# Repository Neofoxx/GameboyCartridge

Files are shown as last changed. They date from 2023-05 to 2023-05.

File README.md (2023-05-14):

# Gameboy Cartridge with a PIC32

A Gameboy cartridge with a microcontroller on it, for quick tests on actual hardware 

## Overview

This projects implements a simple 32kB ROM + 8kB SRAM cartridge, where both are replaced with SRAM chips, and populated by a PIC32MM microcontroller at either boot, or via a USB interface.

Currently working:
- Uploading to the "ROM" part of the cartridge
- Resetting etc.
- Tested that Tetris is playable, if a write to 0x2000 is patched out

Future plans:
- "SRAM" part of cartridge tested
- Speedup of upload/readout scripts

Not planned:
- Bigger size of "ROM"

## Theory of operation

In a normal gameboy cartrdige without an MBC, there is usually just a ROM chip, that contains the game. An exmaple of this would be Tetris. This is memory mapped into the Gameboys address space, and can be 32kB max.

There is also space for an 8kB RAM chip - usually SRAM, which means a battery is required to save the contents. FRAM chips are available nowadays, and remove the battery requirements, at the expense of increased cost. This is also memory mapped, but needs a few logic for address decoding.

In this implementation, both ROM and RAM are replaced with 32kB SRAM chips. One is used as the ROM, the other (well, part of it) is used as SRAM.

The idea is, that for speeds testing on real HW, code can be uploaded from the PC to the Gameboy via the USB connection, removing the need to unplug the cartridge, insert it into the programmer, flash it, remove it, reinstall it, and then test. Convenience is what we're after.

The other idea is for the microcontroller to have a 40kB section of FLASH dedicated to storing said contents, and automatically populating the chips at power-up.

## TODOs

Fix board files. Forgot to connect some pins to the transistors...

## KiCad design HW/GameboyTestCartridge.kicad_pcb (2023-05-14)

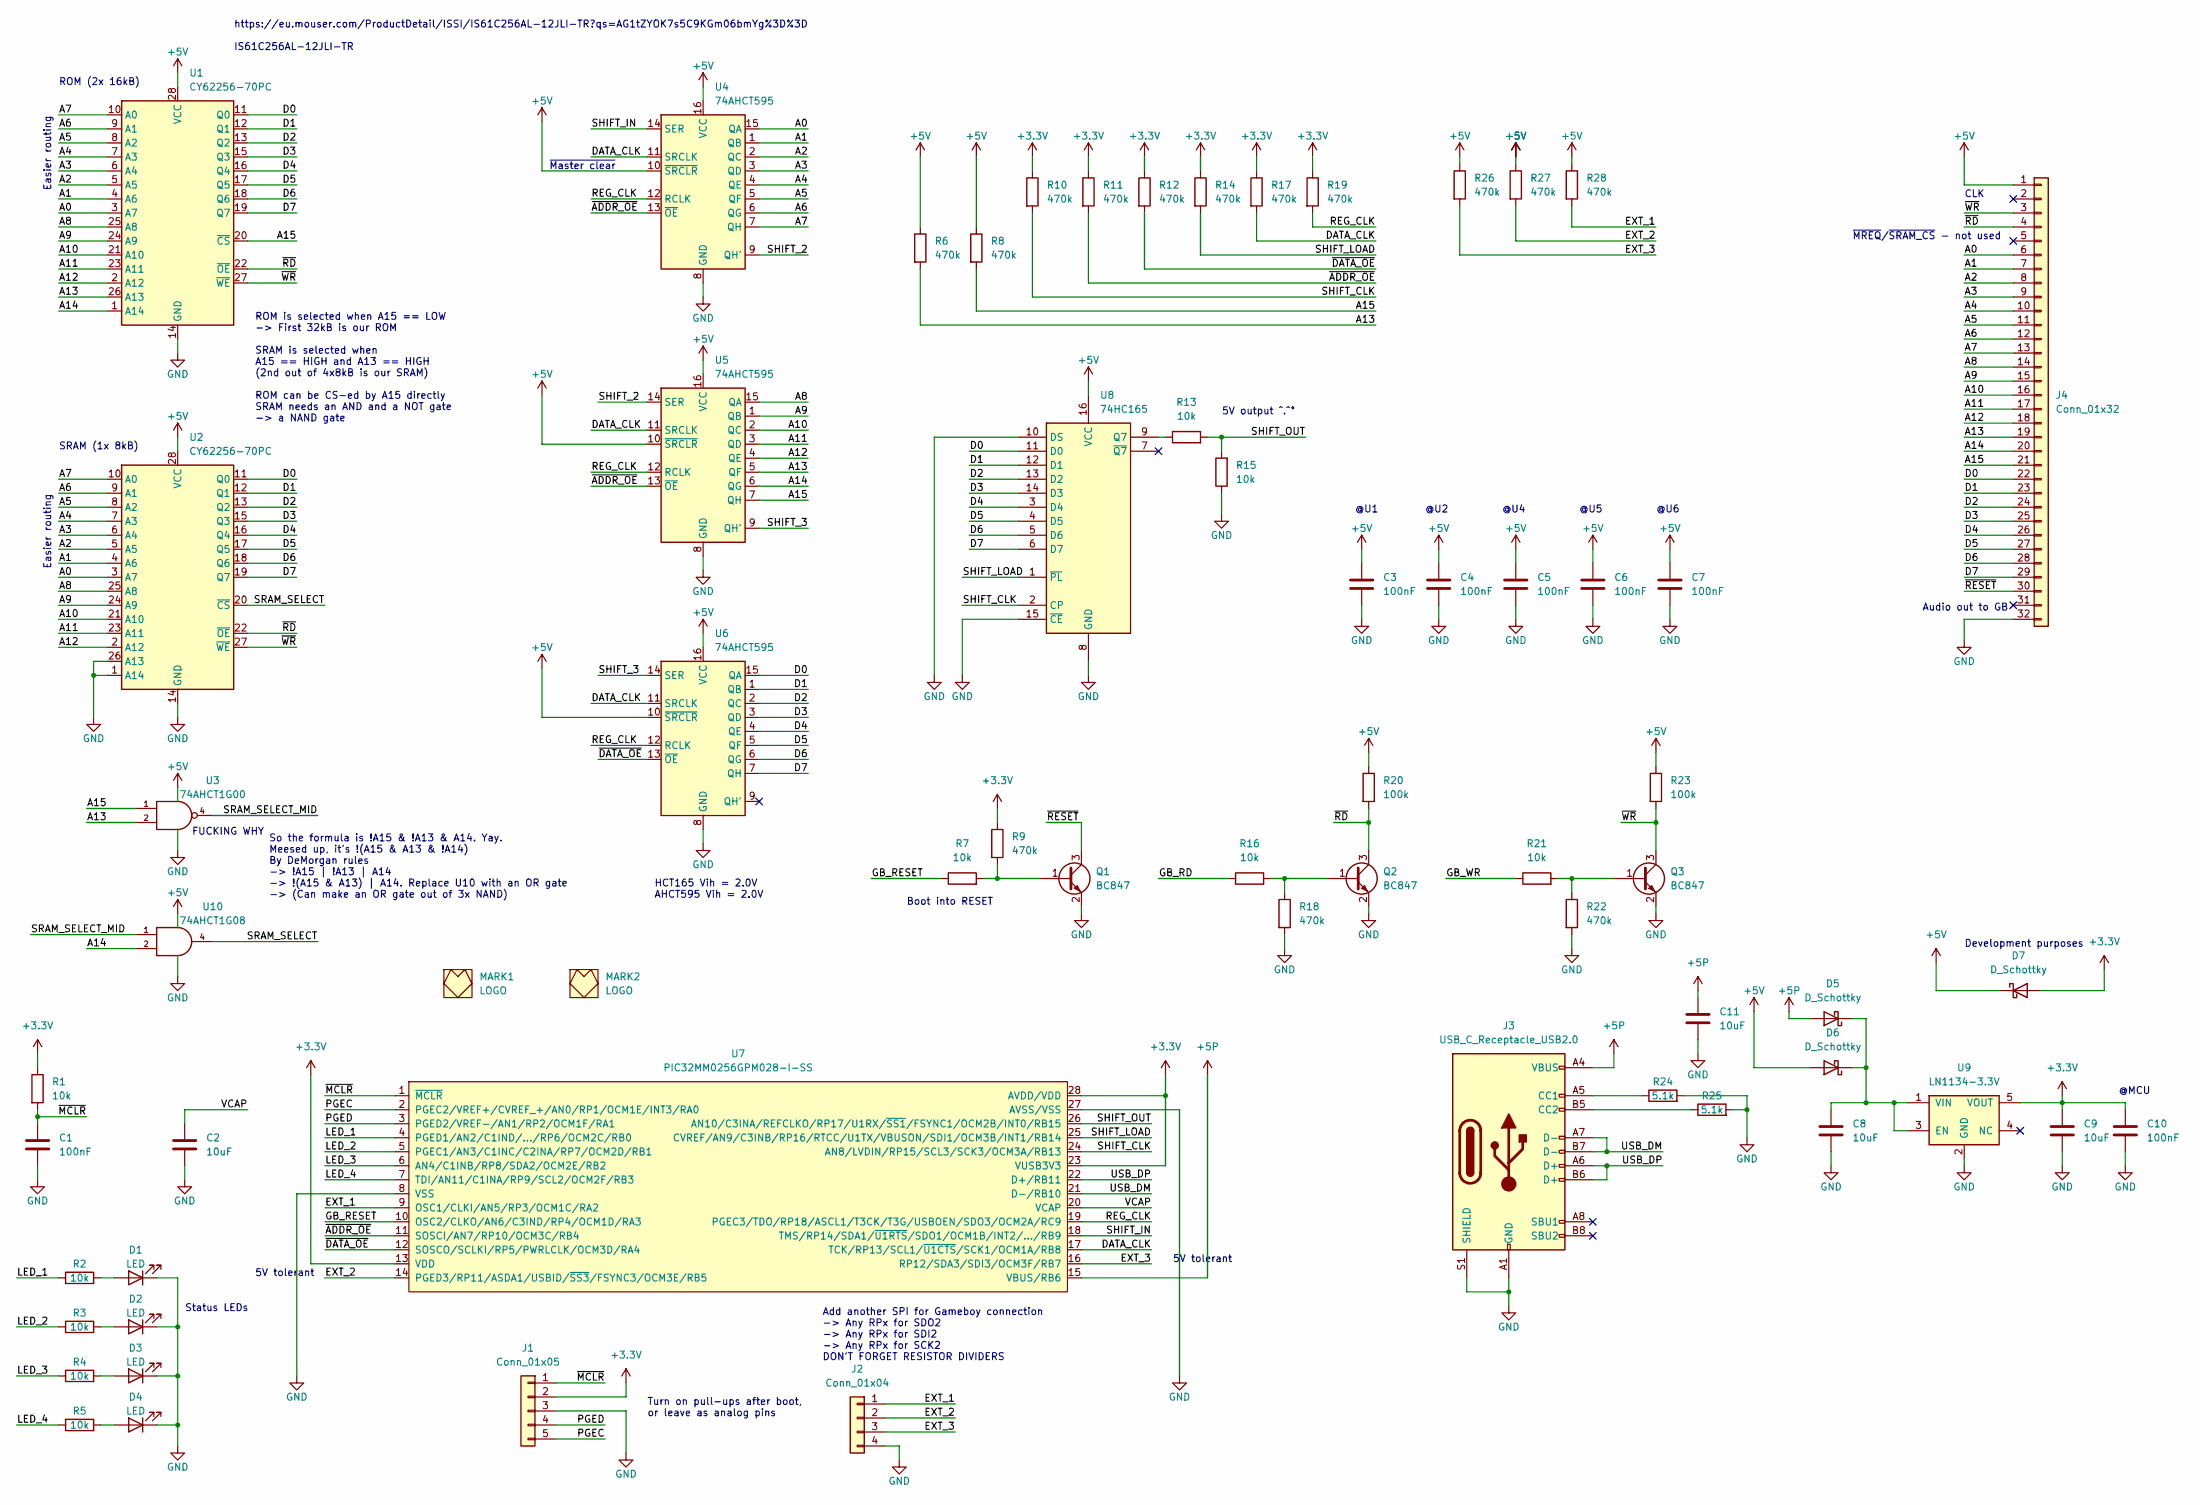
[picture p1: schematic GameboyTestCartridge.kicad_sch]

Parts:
C1, C3, C4, C5, C6, C7, C10: 100nF; C_0603_1608Metric
C2, C8, C9, C11: 10uF; C_0805_2012Metric
D1, D2, D3, D4: LED; LED_0603_1608Metric
D5, D6, D7: D_Schottky; D_SOD-323
J1: Conn_01x05; PinHeader_1x05_P2.54mm_Horizontal
J2: Conn_01x04; PinHeader_1x04_P2.54mm_Horizontal
J3: USB_C_Receptacle_USB2.0; Jing_USB_C_2_0_16pin_receptable_noSlots
J4: Conn_01x32; GameboyCartridge
MARK1: LOGO; FOX_LOGO_MASK
MARK2: LOGO; FOX_LOGO_SILK
Q1, Q2, Q3: BC847; SOT-23
R1, R2, R3, R4, R5, R7, R13, R15, R16, R21: 10k; R_0603_1608Metric
R6, R8, R9, R10, R11, R12, R14, R17, R18, R19, R22, R26, R27, R28: 470k; R_0603_1608Metric
R20, R23: 100k; R_0603_1608Metric
R24, R25: 5.1k; R_0603_1608Metric
U1, U2: CY62256-70PC; SOIC-28W_7.5x17.9mm_P1.27mm
U3: 74AHCT1G00; SOT-23-5
U4, U5, U6: 74AHCT595; SOIC-16_3.9x9.9mm_P1.27mm
U7: PIC32MM0256GPM028-I-SS; SSOP-28_5.3x10.2mm_P0.65mm
U8: 74HC165; SOIC-16_3.9x9.9mm_P1.27mm
U9: LN1134-3.3V; SOT-23-5
U10: 74AHCT1G08; SOT-23-5

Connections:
+3.3V: C9.1, C10.1, D7.2 (A), J1.2, R1.1, R9.1, R10.1, R11.1, R12.1, R14.1, R17.1, R19.1, U7.13 (VDD), U7.23 (VUSB3V3), U7.28 (AVDD/VDD), U9.5 (VOUT)
+5P: C11.1, D5.2 (A), J3.A4 (VBUS), J3.A9 (VBUS), J3.B4 (VBUS), J3.B9 (VBUS), U7.15 (VBUS/RB6)
+5V: C3.1, C4.1, C5.1, C6.1, C7.1, D6.2 (A), D7.1 (K), J4.1, R6.1, R8.1, R20.1, R23.1, R26.1, R27.1, R28.1, U1.28 (VCC), U2.28 (VCC), U3.5 (VCC), U4.10 (~SRCLR), U4.16 (VCC), U5.10 (~SRCLR), U5.16 (VCC), U6.10 (~SRCLR), U6.16 (VCC), U8.16 (VCC), U10.5 (VCC)
/A0: J4.6, U1.3 (A7), U2.3 (A7), U4.15 (QA)
/A1: J4.7, U1.4 (A6), U2.4 (A6), U4.1 (QB)
/A2: J4.8, U1.5 (A5), U2.5 (A5), U4.2 (QC)
/A3: J4.9, U1.6 (A4), U2.6 (A4), U4.3 (QD)
/A4: J4.10, U1.7 (A3), U2.7 (A3), U4.4 (QE)
/A5: J4.11, U1.8 (A2), U2.8 (A2), U4.5 (QF)
/A6: J4.12, U1.9 (A1), U2.9 (A1), U4.6 (QG)
/A7: J4.13, U1.10 (A0), U2.10 (A0), U4.7 (QH)
/A8: J4.14, U1.25 (A8), U2.25 (A8), U5.15 (QA)
/A9: J4.15, U1.24 (A9), U2.24 (A9), U5.1 (QB)
/A10: J4.16, U1.21 (A10), U2.21 (A10), U5.2 (QC)
/A11: J4.17, U1.23 (A11), U2.23 (A11), U5.3 (QD)
/A12: J4.18, U1.2 (A12), U2.2 (A12), U5.4 (QE)
/A13: J4.19, R6.2, U1.26 (A13), U3.2, U5.5 (QF)
/A14: J4.20, U1.1 (A14), U5.6 (QG), U10.2
/A15: J4.21, R8.2, U1.20 (~CS), U3.1, U5.7 (QH)
/D0: J4.22, U1.11 (Q0), U2.11 (Q0), U6.15 (QA), U8.11 (D0)
/D1: J4.23, U1.12 (Q1), U2.12 (Q1), U6.1 (QB), U8.12 (D1)
/D2: J4.24, U1.13 (Q2), U2.13 (Q2), U6.2 (QC), U8.13 (D2)
/D3: J4.25, U1.15 (Q3), U2.15 (Q3), U6.3 (QD), U8.14 (D3)
/D4: J4.26, U1.16 (Q4), U2.16 (Q4), U6.4 (QE), U8.3 (D4)
/D5: J4.27, U1.17 (Q5), U2.17 (Q5), U6.5 (QF), U8.4 (D5)
/D6: J4.28, U1.18 (Q6), U2.18 (Q6), U6.6 (QG), U8.5 (D6)
/D7: J4.29, U1.19 (Q7), U2.19 (Q7), U6.7 (QH), U8.6 (D7)
/DATA_CLK: R17.2, U4.11 (SRCLK), U5.11 (SRCLK), U6.11 (SRCLK), U7.17 (TCK/RP13/SCL1/~U1CTS/SCK1/OCM1A/RB8)
/EXT_1: J2.1, R28.2, U7.9 (OSC1/CLKI/AN5/RP3/OCM1C/RA2)
/EXT_2: J2.2, R27.2, U7.14 (PGED3/RP11/ASDA1/USBID/~SS3/FSYNC3/OCM3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)
/EXT_3: J2.3, R26.2, U7.16 (RP12/SDA3/SDI3/OCM3F/RB7)
/GB_RD: R16.1
/GB_RESET: R7.1, U7.10 (OSC2/CLKO/AN6/C3IND/RP4/OCM1D/RA3)
/GB_WR: R21.1
/LED_1: R2.1, U7.4 (PGED1/AN2/C1IND/.../RP6/OCM2C/RB0)
/LED_2: R3.1, U7.5 (PGEC1/AN3/C1INC/C2INA/RP7/OCM2D/RB1)
/LED_3: R4.1, U7.6 (AN4/C1INB/RP8/SDA2/OCM2E/RB2)
/LED_4: R5.1, U7.7 (TDI/AN11/C1INA/RP9/SCL2/OCM2F/RB3)
/PGEC: J1.5, U7.2 (PGEC2/VREF+/CVREF_+/AN0/RP1/OCM1E/INT3/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)
/PGED: J1.4, U7.3 (PGED2/VREF-/AN1/RP2/OCM1F/RA1)
/REG_CLK: R19.2, U4.12 (RCLK), U5.12 (RCLK), U6.12 (RCLK), U7.19 (PGEC3/TDO/RP18/ASCL1/T3CK/T3G/USBOEN/SD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)
/SHIFT_2: U4.9 (QH'), U5.14 (SER)
/SHIFT_3: U5.9 (QH'), U6.14 (SER)
/SHIFT_CLK: R10.2, U7.24 (AN8/LVDIN/RP15/SCL3/SCK3/OCM3A/RB13), U8.2 (CP)
/SHIFT_IN: U4.14 (SER), U7.18 (TMS/RP14/SDA1/~U1RTS/SDO1/OCM1B/INT2/..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)
/SHIFT_LOAD: R14.2, U7.25 (CVREF/AN9/C3INB/RP16/RTCC/U1TX/VBUSON/S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), U8.1 (~PL)
/SHIFT_OUT: R13.2, R15.2, U7.26 (AN10/C3INA/REFCLKO/RP17/U1RX/~SS1/FSYNC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)
/SRAM_SELECT: U2.20 (~CS), U10.4
/SRAM_SELECT_MID: U3.4, U10.1
/USB_DM: J3.A7 (D-), J3.B7 (D-), U7.21 (D-/RB10)
/USB_DP: J3.A6 (D+), J3.B6 (D+), U7.22 (D+/RB11)
/VCAP: C2.1, U7.20 (VCAP)
/~ADDR_OE: R11.2, U4.13 (~OE), U5.13 (~OE), U7.11 (SOSCI/AN7/RP10/OCM3C/RB4)
/~DATA_OE: R12.2, U6.13 (~OE), U7.12 (SOSCO/SCLKI/RP5/PWRLCLK/OCM3D/RA4)
/~MCLR: C1.1, J1.1, R1.2, U7.1 (~MCLR)
/~RD: J4.4, Q2.3 (C), R20.2, U1.22 (~OE), U2.22 (~OE)
/~RESET: J4.30, Q1.3 (C)
/~WR: J4.3, Q3.3 (C), R23.2, U1.27 (~WE), U2.27 (~WE)
GND: C1.2, C2.2, C3.2, C4.2, C5.2, C6.2, C7.2, C8.2, C9.2, C10.2, C11.2, D1.1 (K), D2.1 (K), D3.1 (K), D4.1 (K), J1.3, J2.4, J3.A1 (GND), J3.A12 (GND), J3.B1 (GND), J3.B12 (GND), J3.S1 (SHIELD), J4.32, Q1.2 (E), Q2.2 (E), Q3.2 (E), R15.1, R18.2, R22.2, R24.2, R25.2, U1.14 (GND), U2.1 (A14), U2.14 (GND), U2.26 (A13), U3.3 (GND), U4.8 (GND), U5.8 (GND), U6.8 (GND), U7.8 (VSS), U7.27 (AVSS/VSS), U8.8 (GND), U8.10 (DS), U8.15 (~CE), U9.2 (GND), U10.3 (GND)
unnamed: C8.1, D5.1 (K), D6.1 (K), U9.1 (VIN), U9.3 (EN)
unnamed: D1.2 (A), R2.2
unnamed: D2.2 (A), R3.2
unnamed: D3.2 (A), R4.2
unnamed: D4.2 (A), R5.2
unnamed: J3.A5 (CC1), R24.1
unnamed: J3.B5 (CC2), R25.1
unnamed: Q1.1 (B), R7.2, R9.2
unnamed: Q2.1 (B), R16.2, R18.1
unnamed: Q3.1 (B), R21.2, R22.1
unnamed: R13.1, U8.9 (Q7)

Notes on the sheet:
ROM is selected when A15 == LOW -> First 32kB is our ROM SRAM is selected when A15 == HIGH and A13 == HIGH (2nd out of 4x8kB is our SRAM) ROM can be CS-ed by A15 directly SRAM needs an AND and a NOT gate -> a NAND gate
HCT165 Vih = 2.0V AHCT595 Vih = 2.0V
Easier routing
5V output ^.^°
Turn on pull-ups after boot, or leave as analog pins
~{Master clear}
@U5
~{MREQ}/~{SRAM_CS} - not used
@U4
FUCKING WHY
@U2
Boot into RESET
So the formula is !A15 & !A13 & A14. Yay. Meesed up, it's !(A15 & A13 & !A14) By DeMorgan rules -> !A15 | !A13 | A14 -> !(A15 & A13) | A14. Replace U10 with an OR gate -> (Can make an OR gate out of 3x NAND)
Add another SPI for Gameboy connection -> Any RPx for SDO2 -> Any RPx for SDI2 -> Any RPx for SCK2 DON'T FORGET RESISTOR DIVIDERS
Audio out to GB
5V tolerant
Development purposes
@U1
Status LEDs
ROM (2x 16kB)
SRAM (1x 8kB)
@U6
https://eu.mouser.com/ProductDetail/ISSI/IS61C256AL-12JLI-TR?qs=AG1tZYOK7s5C9KGm06bmYg%3D%3D IS61C256AL-12JLI-TR
@MCU
CLK

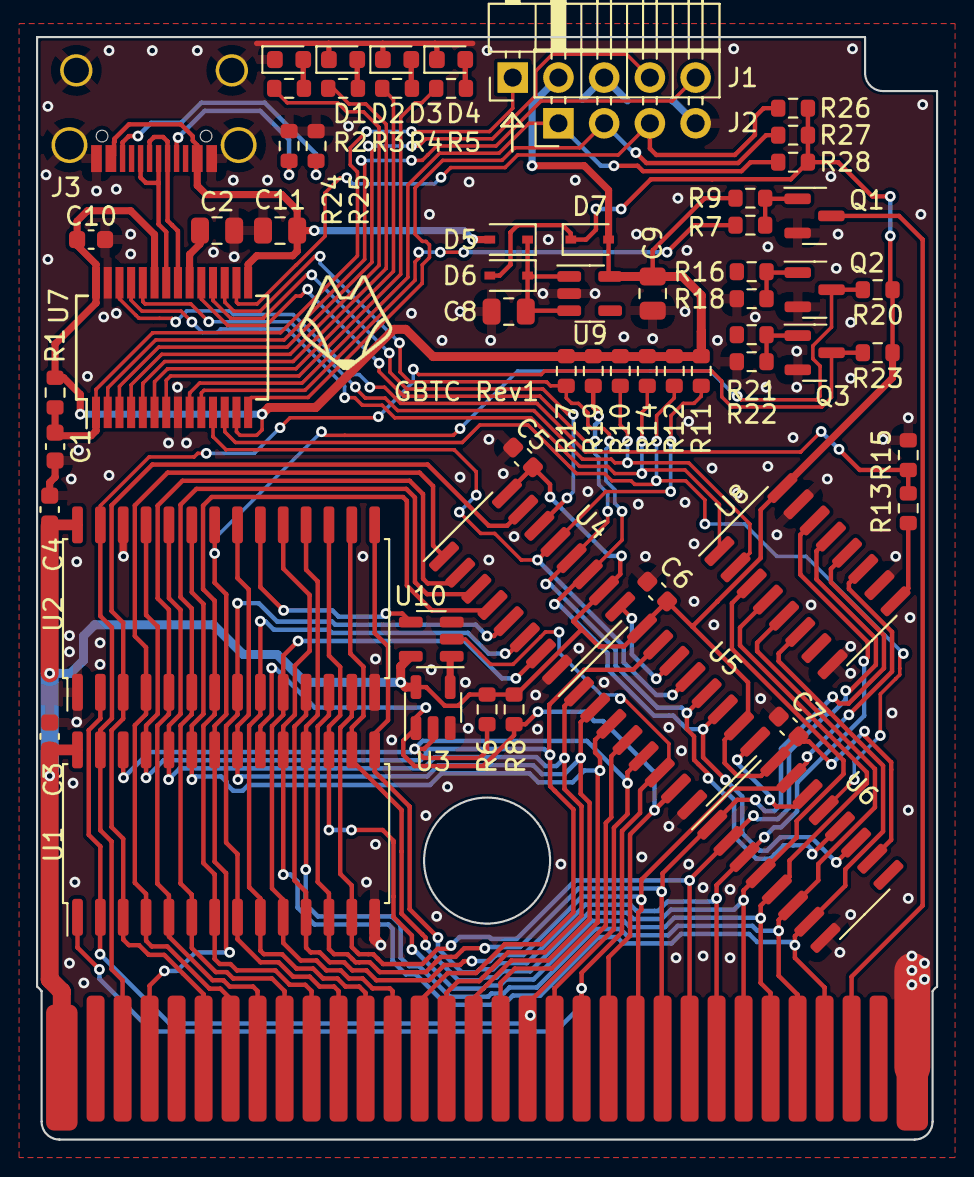
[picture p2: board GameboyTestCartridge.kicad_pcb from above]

Board: 2 copper layers, 50.0 x 61.2 mm, 65 parts (1 on the bottom side), 68 nets.

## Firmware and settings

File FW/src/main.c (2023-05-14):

#include <p32xxxx.h>
#include <const.h>      // MIPS32
#include <inttypes.h>
#include <stdbool.h>
#include <string.h>
#include <stdio.h>
#include <newlib.h>
#include <errno.h>

// Config bits
#include <configBits.h>

// Drivers for HW
#include <GPIODrv.h>
#include <LED.h>
// USB
#include <usb.h>
#include <usb_config.h>
#include <usb_ch9.h>
#include <usb_cdc.h>
// COMMS - usb and UART
#include <COMMS.h>
// Interrupts
#include <interrupt.h>

// Commands
#include <commandExecutor.h>

// Delay
#include <support.h>

char inBuf[2048];

// Not actually used
static struct cdc_line_coding line_coding =
{
	115200,
	CDC_CHAR_FORMAT_1_STOP_BIT,
	CDC_PARITY_NONE,
	8,
};

volatile uint32_t packetCounter = 0;	// Reset by SOF. May be useful


// TODO - run the timer, like in MX440 example (SysTick style)
// TODO2 - there should be an implementation, that uses the 24MHz/2 clock using CP0
void simpleDelay(unsigned int noOfLoops){
    unsigned int i = 0;
    while (i<noOfLoops){
        i++;
        asm("nop");
    }
}

void setup(){

	// Disable JTAG pins!

	GPIODrv_init();
	LED_init();
	
    // Check, there was a bug in one of the versions...
	//uint32_t * ANSELB_REAL = (uint32_t *)0xBF802BB0;
	//ANSELB_REAL[0] = 0;

	// Copied for USB, from hardware.c
	IPC7bits.USBIP = 4;

	// Enable interrupts - at the end, otherwise setting priorities is ineffective ? TODO
	//INTEnableSystemMultiVectoredInt();
	// PIC32MM needs some hand work
	SYSKEY = 0x00000000;      // force lock
	SYSKEY = 0xAA996655;      // unlock
	SYSKEY = 0x556699AA; 

	SPLLCON = (0b010 << 24)	// PLLODIV = PLL divide-by-4, so we get 24MHZ from 96MHz
		| (0b0000101 << 16)		// PLLMULT = x12, so 8MHz * 12 = 96MHz
		| (0b1 << 7);			// FRC is selected as input to PLL

	simpleDelay(1000);

	OSCCONbits.NOSC = 1;	// Switch to SPLL
	
	OSCCONSET = 1;		// Sets the OSWEN bit, that forces a change to news settings in NOSC
	
	SYSKEY = 0x00000000;    // force lock

	simpleDelay(100000);


	// Setup oscillator tuning, because we're too cool for crystals
	SYSKEY = 0x00000000;      // force lock
	SYSKEY = 0xAA996655;      // unlock
	SYSKEY = 0x556699AA; 
	
	OSCTUN = (1<<12) 		// SOSC host clock used to tune
		| (0b100000 << 0);	// Set to -1.5% off, just to see on scope.	
		
	simpleDelay(400000);	
		
	OSCTUNSET = (1<<15);	// Set ON bit, to start tuning.	
	
	SYSKEY = 0x00000000;      // force lock

	simpleDelay(100000);
	
	REFO1TRIM = 0;
	
	REFO1CON = (48 << 16)	// Divde input by 2*(val + TRIM/512). 2 == 4
		| (1 << 15)			// ON bit
		| (0 << 12)			// NOT Driven on REFO1 pin
		| (1 << 11)			// Continues in sleep mode
		| (0b0111);			// PLL VCO is input to REFCLK
	
	
	
	
	// Basically INTEnableSystemMultiVectoredInt
	// Enable multi-vectored mode
	//INTCONSET = _INTCON_MVEC_MASK;
	//INTCON = INTCON | _INTCON_MVEC_MASK;
	INTCONbits.MVEC=1; 

	// Interrupt exceptions use their own dedication exception vector offset (0x200), when CAUSE_IV is set to 1
	_CP0_BIS_CAUSE(_CP0_CAUSE_IV_MASK);

	// set the CP0 status IE bit high to turn on interrupts
	//INTEnableInterrupts();
	asm("ei");
	
}


int main(){

	setup();
	usb_init();
	
	IEC0bits.USBIE = 1;

	char outBuf[128];
	int len;

	int counter = 0;



	for(;;){
	
		len = sprintf(outBuf, "This is a test %d %d\n", counter++, COMMS_helper_dataLen(&uartRXstruct));

		//COMMS_helper_addToBuf(&uartTXstruct, (uint8_t *)outBuf, len);

		// At this point, check if there is a \n in the input buffer
		// If there isn't a \n for x chars, clear buffer or something
		// If there is, go parse the string.

		//delayMs(500);

		int32_t elements = COMMS_helper_checkNewline(&uartRXstruct);
		if (elements > 0){
			COMMS_helper_getData(&uartRXstruct, elements, (uint8_t *)inBuf);
			inBuf[elements] = 0;		// Null terminate
			inBuf[elements - 1] = 0;	// Delete newline

			commandExecutor(inBuf);

		}

		// Unused
		#ifndef USB_USE_INTERRUPTS
		usb_service();
		#endif

	}

    return(0);
    
}




/////////////////////////////////////////////////////////////7

#ifdef USB_USE_INTERRUPTS
#if defined (__PIC32MX__)

INTERRUPT(USB1Interrupt){

#elif defined (__PIC32MM__)

INTERRUPT(USBInterrupt){

#endif
  usb_service();  // Deal with USB stuff

  // All of the cases depend on this anyway.
  if (!usb_is_configured()){
    return;
  }

  // Priorities!

  // 3. We have one IN (us->PC) endpoint 
  // 2. We have one OUT (PC->us) endpoint


  ////////////////////////////////////////////////////////////
  // 2. Get data from EP2 OUT (PC to us)
  ////////////////////////////////////////////////////////////
  if (!usb_out_endpoint_halted(EP_UARTINTERFACE_NUM) && usb_out_endpoint_has_data(EP_UARTINTERFACE_NUM) && !usb_in_endpoint_busy(EP_UARTINTERFACE_NUM)) {

    if (!COMMS_uartRX_addToBuf()){
      // Packet is consumed regardless
    }

  }

  ////////////////////////////////////////////////////////////
  // 3. Push data to EP2 IN (us to PC)
  ////////////////////////////////////////////////////////////

  // Post data to EP2 IN (us to PC)
  if (!usb_in_endpoint_halted(EP_UARTINTERFACE_NUM) && !usb_in_endpoint_busy(EP_UARTINTERFACE_NUM)){
    if (!COMMS_USB_uartTX_transmitBuf()){
      // Packet is consumed regardless
    }
  }

}
#endif


/* Callbacks. These function names are set in usb_config.h. */
void app_set_configuration_callback(uint8_t configuration)
{

}

uint16_t app_get_device_status_callback()
{
	return 0x0000;
}

void app_endpoint_halt_callback(uint8_t endpoint, bool halted){
	// This is a notification only.  There is no way to reject this request.
}

int8_t app_set_interface_callback(uint8_t interface, uint8_t alt_setting){
	// The callback should return 0 if the new alternate setting can be set or -1 if
	// it cannot. This callback is completely unnecessary if you only have one
	// alternate setting (alternate setting zero) for each interface.
	return 0;
}

int8_t app_get_interface_callback(uint8_t interface){
	// The application should return the interface's current alternate setting
	return 0;
}

void app_out_transaction_callback(uint8_t endpoint){
	// If we wanted, we can use this function to trigger when the
	// OUT transaction on the endpoint is finished (PC->us), and read
	// data out fast that way. Unnecessary for now.
}

void app_in_transaction_complete_callback(uint8_t endpoint){
	// If we wanted, we can use this function to trigger when the
	// IN transaction on the endpoint is finished (us->PC), and rearm/send
	// data fast that way. Unnecessary for now.
}

int8_t app_unknown_setup_request_callback(const struct setup_packet *setup){
	/* To use the CDC device class, have a handler for unknown setup
	 * requests and call process_cdc_setup_request() (as shown here),
	 * which will check if the setup request is CDC-related, and will
	 * call the CDC application callbacks defined in usb_cdc.h. For
	 * composite devices containing other device classes, make sure
	 * MULTI_CLASS_DEVICE is defined in usb_config.h and call all
	 * appropriate device class setup request functions here.
	 */
	// Since we only use (dual) CDC, cdc_setup_request is enough, it gets called twise.
	return process_cdc_setup_request(setup);
}

int16_t app_unknown_get_descriptor_callback(const struct setup_packet *pkt, const void **descriptor){
	// Called when a GET_DESCRIPTOR request is received from
	// the host for a descriptor which is unrecognized by the USB stack.
	return -1;
}

void app_start_of_frame_callback(void){
	// Interrupt at SOF
}

void app_usb_reset_callback(void){
	// Possibly reset USB buffer, or setup DMAs or something.
	// Unnecessary for now.
}

/* CDC Callbacks. See usb_cdc.h for documentation. */

int8_t app_send_encapsulated_command(uint8_t interface, uint16_t length){
	// Unsure what to support here.
	return -1;
}

int16_t app_get_encapsulated_response(uint8_t interface,
                                      uint16_t length, const void **report,
                                      usb_ep0_data_stage_callback *callback,
                                      void **context){
	// Unsure what to support here.
	return -1;
}

int8_t app_set_comm_feature_callback(uint8_t interface, bool idle_setting, bool data_multiplexed_state){
  return -1;
}

int8_t app_clear_comm_feature_callback(uint8_t interface, bool idle_setting, bool data_multiplexed_state){
  return -1; 
}

int8_t app_get_comm_feature_callback(uint8_t interface, bool *idle_setting, bool *data_multiplexed_state){
  return -1;
}

int8_t app_set_line_coding_callback(uint8_t interface, const struct cdc_line_coding *coding){

  // Check if values are in ranges we support
  // Technically we should just ignore this, but leave in as is anyway
  if (coding->dwDTERate <= 1000000
    && (coding->bCharFormat == CDC_CHAR_FORMAT_1_STOP_BIT || coding->bCharFormat == CDC_CHAR_FORMAT_2_STOP_BITS)
    && coding->bParityType == CDC_PARITY_NONE
    && coding->bDataBits == 8){

    line_coding = *coding;
  }

  return 0;	// No way to deny. Must return 0, otherwise it will stall.
}

int8_t app_get_line_coding_callback(uint8_t interface, struct cdc_line_coding *coding){
  // Return what sort of line_coding we are using.
  *coding = line_coding;
  return 0;
}

int8_t app_set_control_line_state_callback(uint8_t interface, bool dtr, bool rts){
  // Set DTR and RTS lines, according to demands.
  // No interface currently supports this

  return 0;
}

int8_t app_send_break_callback(uint8_t interface, uint16_t duration){
	return 0;
}

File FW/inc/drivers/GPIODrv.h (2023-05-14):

#ifndef GPIODRV_H_573f2ca8b43e44209acc90f0f9b7de5d
#define GPIODRV_H_573f2ca8b43e44209acc90f0f9b7de5d

#include <p32xxxx.h>
#include <inttypes.h>

#define GPIO_LOW		0
#define GPIO_HIGH		1

// LED_1
#define LED_1_TRISbits	    TRISBbits
#define LED_1_TRISPIN	    TRISB0
#define LED_1_LATbits	    LATBbits
#define LED_1_LATPIN	    LATB0
#define LED_1_LATINV	    LATBINV
#define LED_1_MASK	    (1<<0)
#define LED_1_ANSEL_REG     ANSELBbits
#define LED_1_ANSEL_BIT     ANSB0

// LED_2
#define LED_2_TRISbits	    TRISBbits
#define LED_2_TRISPIN	    TRISB1
#define LED_2_LATbits	    LATBbits
#define LED_2_LATPIN	    LATB1
#define LED_2_LATINV        LATBINV
#define LED_2_MASK          (1<<1)
#define LED_2_ANSEL_REG     ANSELBbits
#define LED_2_ANSEL_BIT     ANSB1

// LED_3 / WR
#define WR_TRISbits	    TRISBbits
#define WR_TRISPIN	    TRISB2
#define WR_LATbits	    LATBbits
#define WR_LATPIN	    LATB2
#define WR_LATINV	    LATBINV
#define WR_MASK		    (1<<2)
#define WR_ANSEL_REG        ANSELBbits
#define WR_ANSEL_BIT        ANSB2

// LED_4 / RD
#define RD_TRISbits	    TRISBbits
#define RD_TRISPIN	    TRISB3
#define RD_LATbits	    LATBbits
#define RD_LATPIN	    LATB3
#define RD_LATINV           LATBINV
#define RD_MASK             (1<<3)
#define RD_ANSEL_REG        ANSELBbits
#define RD_ANSEL_BIT        ANSB3

// GB_RESET pin
#define GB_RESET_TRISbits   TRISAbits
#define GB_RESET_TRISPIN    TRISA3
#define GB_RESET_LATbits    LATAbits
#define GB_RESET_LATPIN	    LATA3
#define GB_RESET_LATINV	    LATAINV
#define GB_RESET_MASK	    (1<<3)

// EXT 1-3 pins, used for SPI slave (someday...)
#define EXT_1_TRISbits	        TRISAbits
#define EXT_1_TRISPIN		TRISA2
#define EXT_1_LATbits	        LATAbits
#define EXT_1_LATPIN		LATA2
#define EXT_1_LATINV		LATAINV
#define EXT_1_MASK		(1<<2)

#define EXT_2_TRISbits	        TRISBbits
#define EXT_2_TRISPIN		TRISB5
#define EXT_2_LATbits	        LATBbits
#define EXT_2_LATPIN		LATB5
#define EXT_2_LATINV		LATAINV
#define EXT_2_MASK		(1<<5)

#define EXT_3_TRISbits	        TRISBbits
#define EXT_3_TRISPIN		TRISB7
#define EXT_3_LATbits	        LATBbits
#define EXT_3_LATPIN		LATB7
#define EXT_3_LATINV		LATBINV
#define EXT_3_MASK		(1<<7)

// 74HC165 Paralell-to-Serial shifter (SPI?)
#define SHIFT_LOAD_TRISbits     TRISBbits
#define SHIFT_LOAD_TRISPIN      TRISB14
#define SHIFT_LOAD_LATbits      LATBbits
#define SHIFT_LOAD_LATPIN       LATB14
#define SHIFT_LOAD_LATINV       LATBINV
#define SHIFT_LOAD_MASK	        (1<<14)
#define SHIFT_LOAD_ANSEL_REG    ANSELBbits
#define SHIFT_LOAD_ANSEL_BIT    ANSB14

#define SHIFT_CLK_TRISbits      TRISBbits
#define SHIFT_CLK_TRISPIN        TRISB13
#define SHIFT_CLK_LATbits       LATBbits
#define SHIFT_CLK_LATPIN        LATB13
#define SHIFT_CLK_LATINV        LATBINV
#define SHIFT_CLK_MASK	        (1<<13)
#define SHIFT_CLK_ANSEL_REG     ANSELBbits
#define SHIFT_CLK_ANSEL_BIT     ANSB13

#define SHIFT_OUT_TRISbits      TRISBbits
#define SHIFT_OUT_TRISPIN       TRISB15
#define SHIFT_OUT_LATbits       LATBbits
#define SHIFT_OUT_LATPIN        LATB15
#define SHIFT_OUT_LATINV        LATBINV
#define SHIFT_OUT_MASK	        (1<<15)
#define SHIFT_OUT_PORTbits      PORTBbits
#define SHIFT_OUT_PORTPIN       RB15
#define SHIFT_OUT_ANSEL_REG     ANSELBbits
#define SHIFT_OUT_ANSEL_BIT     ANSB15

// 74HC595 Serial-in Paralell-out shifters, 3 in chain. (SPI?)
// nADDR_OE - output enable for the two register on the address pins
#define nADDR_OE_TRISbits       TRISBbits
#define nADDR_OE_TRISPIN         TRISB4
#define nADDR_OE_LATbits        LATBbits
#define nADDR_OE_LATPIN         LATB4
#define nADDR_OE_LATINV         LATBINV
#define nADDR_OE_MASK	        (1<<4)
// nDATA_OE - output enable for the one register on the data pins
#define nDATA_OE_TRISbits       TRISAbits
#define nDATA_OE_TRISPIN         TRISA4
#define nDATA_OE_LATbits        LATAbits
#define nDATA_OE_LATPIN         LATA4
#define nDATA_OE_LATINV         LATAINV
#define nDATA_OE_MASK	        (1<<4)

#define REG_CLK_TRISbits        TRISCbits
#define REG_CLK_TRISPIN         TRISC9
#define REG_CLK_LATbits         LATCbits
#define REG_CLK_LATPIN          LATC9
#define REG_CLK_LATINV          LATCINV
#define REG_CLK_MASK	        (1<<9)

#define SHIFT_IN_TRISbits       TRISBbits
#define SHIFT_IN_TRISPIN        TRISB9
#define SHIFT_IN_LATbits        LATBbits
#define SHIFT_IN_LATPIN         LATB9
#define SHIFT_IN_LATINV         LATBINV
#define SHIFT_IN_MASK	        (1<<9)

#define DATA_CLK_TRISbits       TRISBbits
#define DATA_CLK_TRISPIN        TRISB8
#define DATA_CLK_LATbits        LATBbits
#define DATA_CLK_LATPIN         LATB8
#define DATA_CLK_LATINV         LATBINV
#define DATA_CLK_MASK	        (1<<8)

// Function definitons
void GPIODrv_init();

void GPIODrv_setRD(uint8_t state);
void GPIODrv_setWR(uint8_t state);
void GPIODrv_setRST(uint8_t state);
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

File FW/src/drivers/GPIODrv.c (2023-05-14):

#include <p32xxxx.h>
#include <GPIODrv.h>
#include <inttypes.h>
#include <forNewlib.h>

void GPIODrv_init(){
  // Setup initial pin states
  LED_1_ANSEL_REG.LED_1_ANSEL_BIT = 0;  // Turn analog inputs into digital IO
  LED_1_TRISbits.LED_1_TRISPIN = 0;       // Set to output
  LED_1_LATbits.LED_1_LATPIN = 1;       // Show activity
  
  LED_2_ANSEL_REG.LED_2_ANSEL_BIT = 0;  // Turn analog inputs into digital IO
  LED_2_TRISbits.LED_2_TRISPIN = 0;      // Set to output
  LED_2_LATbits.LED_2_LATPIN = 1;       // Show activity
  
  WR_ANSEL_REG.WR_ANSEL_BIT = 0;  // Turn analog inputs into digital IO
  WR_TRISbits.WR_TRISPIN = 0;     // Set to output
  WR_LATbits.WR_LATPIN = 0;       // Deassert
  
  RD_ANSEL_REG.RD_ANSEL_BIT = 0;  // Turn analog inputs into digital IO
  RD_TRISbits.RD_TRISPIN = 0;     // Set to output
  RD_LATbits.RD_LATPIN = 0;       // Deassert
  
  GB_RESET_TRISbits.GB_RESET_TRISPIN = 0;     // Set to output
  GB_RESET_LATbits.GB_RESET_LATPIN = 1;       // Keep asserted
  
  EXT_1_TRISbits.EXT_1_TRISPIN = 1;     // Set to input
  EXT_2_TRISbits.EXT_2_TRISPIN = 1;     // Set to input
  EXT_2_TRISbits.EXT_2_TRISPIN = 1;     // Set to input
  
  SHIFT_LOAD_ANSEL_REG.SHIFT_LOAD_ANSEL_BIT = 0;  // Turn analog inputs into digital IO
  SHIFT_LOAD_TRISbits.SHIFT_LOAD_TRISPIN = 0;     // Set to output
  SHIFT_LOAD_LATbits.SHIFT_LOAD_LATPIN = 1;       // SHIFT == 1, 0 == LOAD
  
  SHIFT_CLK_ANSEL_REG.SHIFT_CLK_ANSEL_BIT = 0;  // Turn analog inputs into digital IO
  SHIFT_CLK_TRISbits.SHIFT_CLK_TRISPIN = 0;     // Set to output
  SHIFT_CLK_LATbits.SHIFT_CLK_LATPIN = 0;       // Deassert CLK
 
  SHIFT_OUT_ANSEL_REG.SHIFT_OUT_ANSEL_BIT = 0;  // Turn analog inputs into digital IO
  SHIFT_OUT_TRISbits.SHIFT_OUT_TRISPIN = 1;   // Set to input
  
  nADDR_OE_TRISbits.nADDR_OE_TRISPIN = 0;   // Set to output
  nADDR_OE_LATbits.nADDR_OE_LATPIN = 1;     // Deassert
  
  nDATA_OE_TRISbits.nDATA_OE_TRISPIN = 0;   // Set to output
  nDATA_OE_LATbits.nDATA_OE_LATPIN = 1;     // Deassert
  
  REG_CLK_TRISbits.REG_CLK_TRISPIN = 0;     // Set to output
  REG_CLK_LATbits.REG_CLK_LATPIN = 0;       // Deassert
  
  SHIFT_IN_TRISbits.SHIFT_IN_TRISPIN = 0;   // Set to output
  SHIFT_IN_LATbits.SHIFT_IN_LATPIN = 0;    // DNC
  
  DATA_CLK_TRISbits.DATA_CLK_TRISPIN = 0;   // Set to output
  DATA_CLK_LATbits.DATA_CLK_LATPIN = 0;     // TODO check later
 
}

void GPIODrv_setRD(uint8_t state){
  if (state){
    RD_LATbits.RD_LATPIN = 1;
  }
  else{
    RD_LATbits.RD_LATPIN = 0;
  }
}

void GPIODrv_setWR(uint8_t state){
  if (state){
    WR_LATbits.WR_LATPIN = 1;
  }
  else{
    WR_LATbits.WR_LATPIN = 0;
  }
}

void GPIODrv_setRST(uint8_t state){
  if (state){
    GB_RESET_LATbits.GB_RESET_LATPIN = 1;
  }
  else{
    GB_RESET_LATbits.GB_RESET_LATPIN = 0;
  }
}

// 595 shift register - SHIFT_IN, DATA_CLK, REG_CLK, ADDR_OE, DATA_OE
void GPIODrv_setSHIFTIN(uint8_t state){
  if (state){
    SHIFT_IN_LATbits.SHIFT_IN_LATPIN = 1;
  }
  else{
    SHIFT_IN_LATbits.SHIFT_IN_LATPIN = 0;
  }
}

void GPIODrv_setDATACLK(uint8_t state){
  if (state){
    DATA_CLK_LATbits.DATA_CLK_LATPIN = 1;
  }
  else{
    DATA_CLK_LATbits.DATA_CLK_LATPIN = 0;
  }
}

void GPIODrv_setREGCLK(uint8_t state){
  if (state){
    REG_CLK_LATbits.REG_CLK_LATPIN = 1;
  }
  else{
    REG_CLK_LATbits.REG_CLK_LATPIN = 0;
  }
}

void GPIODrv_setADDROE(uint8_t state){
  if (state){
    nADDR_OE_LATbits.nADDR_OE_LATPIN = 1;
  }
  else{
    nADDR_OE_LATbits.nADDR_OE_LATPIN = 0;
  }
}

void GPIODrv_setDATAOE(uint8_t state){
  if (state){
    nDATA_OE_LATbits.nDATA_OE_LATPIN = 1;
  }
  else{
    nDATA_OE_LATbits.nDATA_OE_LATPIN = 0;
  }
}

// 165 shift register - SHIFT_LOAD, SHIFT_CLK, SHIFT_OUT (input)
void GPIODrv_setSHIFTLOAD(uint8_t state){
  if (state){
    SHIFT_LOAD_LATbits.SHIFT_LOAD_LATPIN = 1;
  }
  else{
    SHIFT_LOAD_LATbits.SHIFT_LOAD_LATPIN = 0;
  }
}

void GPIODrv_setSHIFTCLK(uint8_t state){
  if (state){
    SHIFT_CLK_LATbits.SHIFT_CLK_LATPIN = 1;
  }
  else{
    SHIFT_CLK_LATbits.SHIFT_CLK_LATPIN = 0;
  }
}

uint32_t GPIODrv_getSHIFTOUT(){
  return SHIFT_OUT_PORTbits.SHIFT_OUT_PORTPIN;
}
